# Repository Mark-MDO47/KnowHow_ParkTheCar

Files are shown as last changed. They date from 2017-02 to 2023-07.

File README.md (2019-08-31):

# KnowHow_ParkTheCar
inspired by TWIT.TV KnowHow Episode 178 about Arduino Collision Avoidance
https://twit.tv/shows/know-how/episodes/178

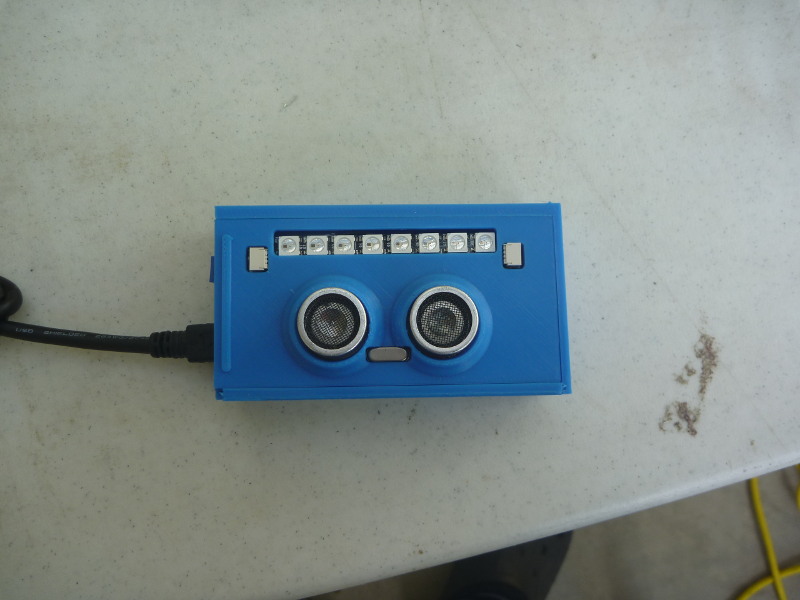
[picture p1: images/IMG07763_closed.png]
Finished version of Park The Car

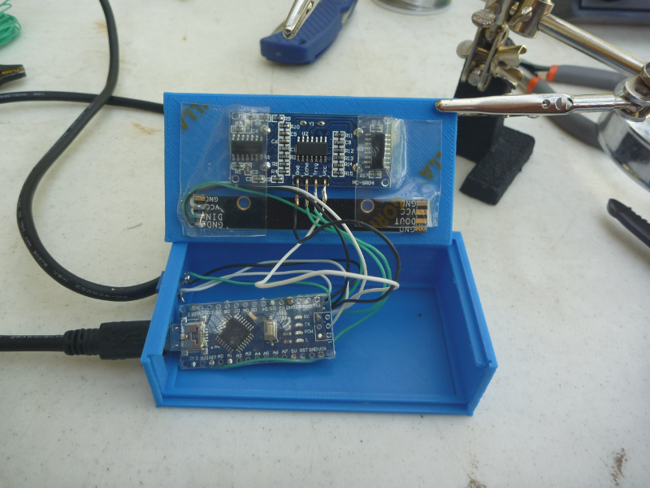
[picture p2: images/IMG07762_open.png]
Open version of Park The Car

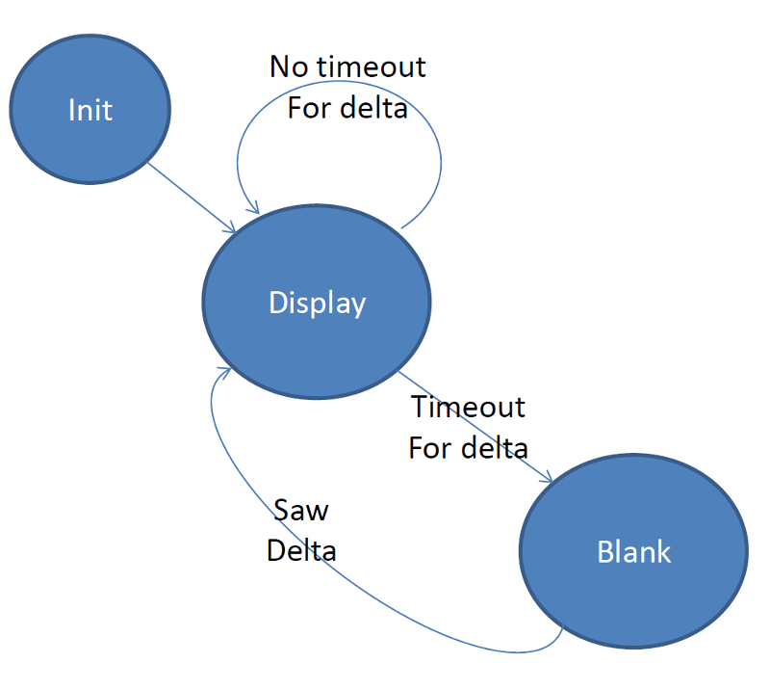
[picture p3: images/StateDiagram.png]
State Diagram of Park The Car


Arduino code rewritten extensively

Enclosure pretty much designed from scratch using OpenSCAD

Used VERY handy OpenSCAD routine from WarrantyVoider, published May 26, 2011 http://www.thingiverse.com/thing:8812
see README_attributions

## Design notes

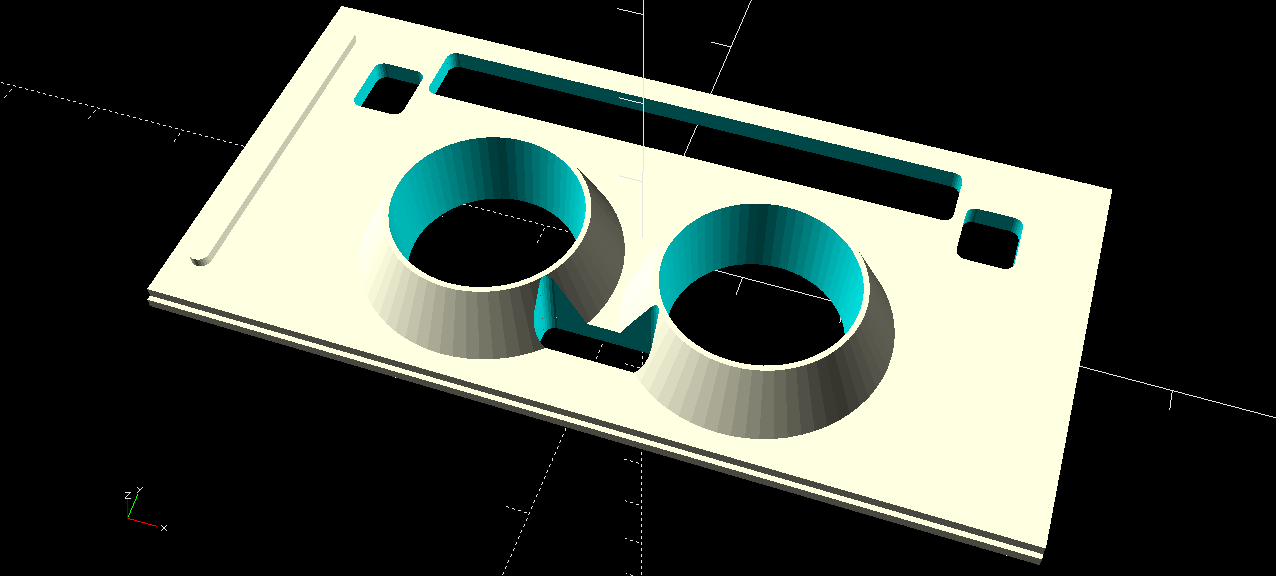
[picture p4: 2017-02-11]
images/top_HC-SR04.png

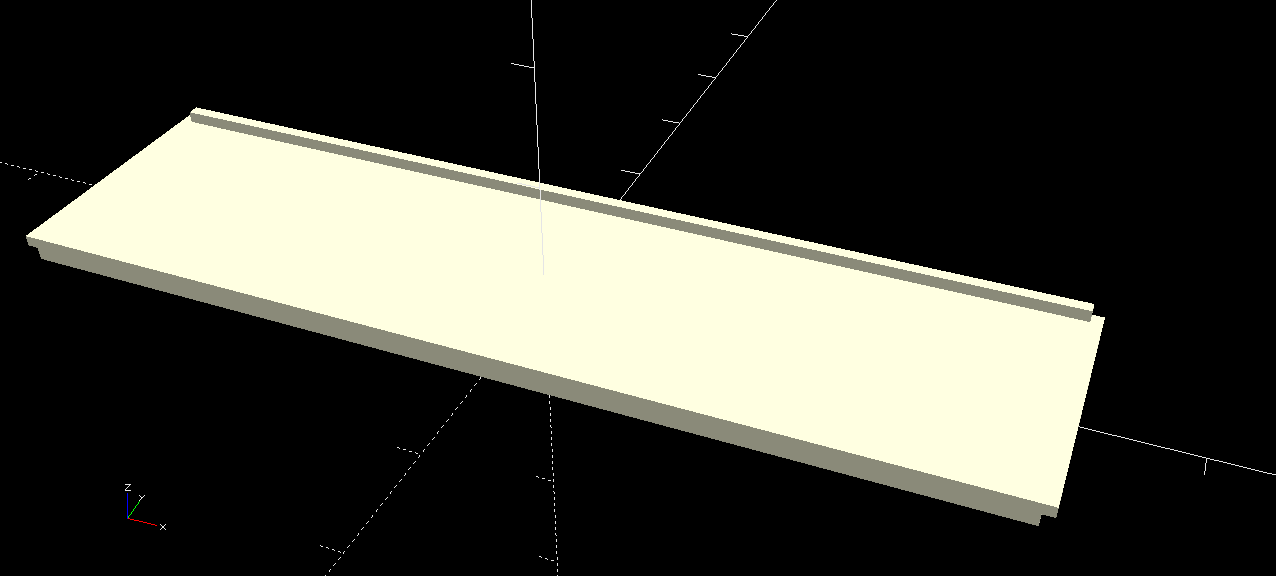
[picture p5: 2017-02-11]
images/side_HC-SR04.png

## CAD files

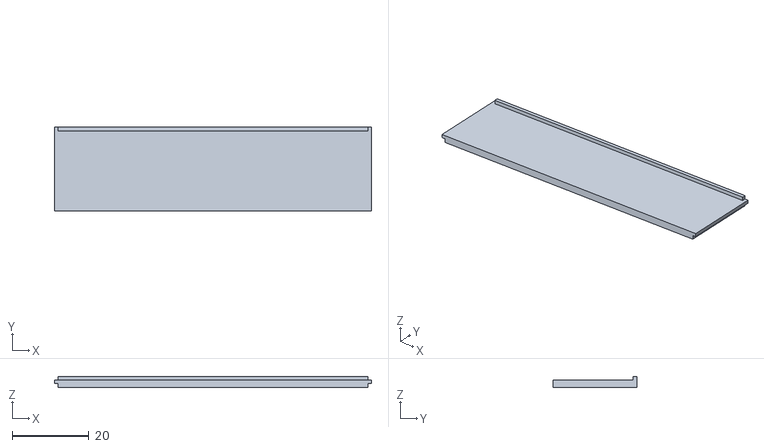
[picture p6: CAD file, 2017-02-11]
3D_Print_Files/side_HC-SR04.stl
82.8 x 21.9 x 3.00

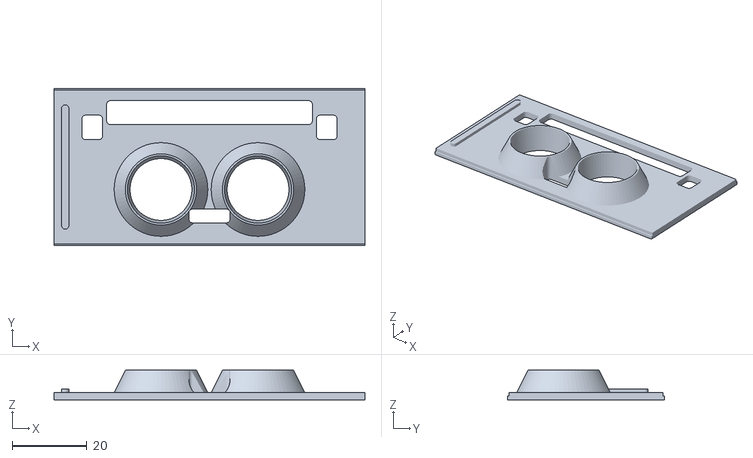
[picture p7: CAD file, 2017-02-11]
3D_Print_Files/top_HC-SR04.stl
83.0 x 42.0 x 8.00

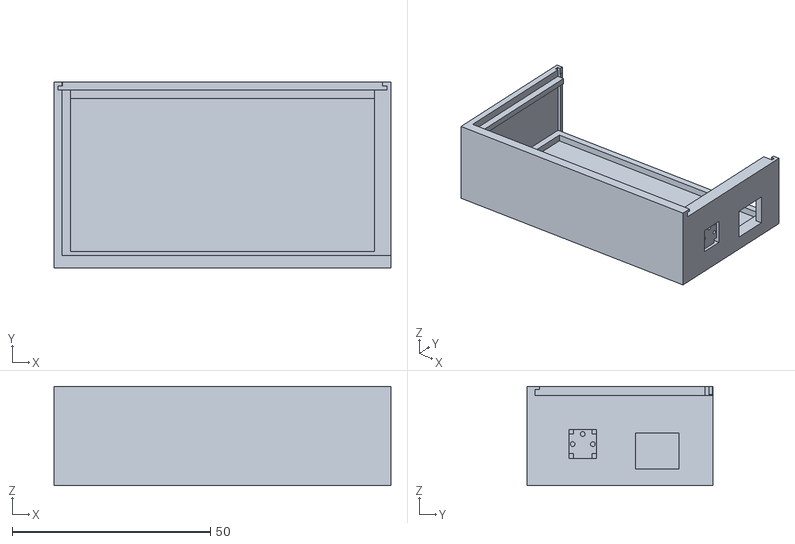
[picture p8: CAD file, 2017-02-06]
3D_Print_Files/box_HC-SR04.stl
85.0 x 47.0 x 25.0

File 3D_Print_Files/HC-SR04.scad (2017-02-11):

/* HC-SR04 enclosure
   2017-01-20 Mark Olson

*/


// VERY handy routine from WarrantyVoider, published May 26, 2011
use<roundCornersCube.scad> // http://www.thingiverse.com/thing:8812

/*

plate = top of box, rectangle
uson  = ultrasonic sensor HC-SR04
led   = LED strip (8 LEDs)
pot   = trimmer pot in UXcell type package 3362P-103

uson:
    Measured total rectangle skinny 20.25 mm (without connectors)
    Measured total rectangle skinny 26.68 mm (with connectors)
    Measured connector sticks out    6.43 mm (use 10 for room in box)
    Measured total rectangle long   45.55 mm
    Measured center circle to end of connector sticks out = 16.555 mm

    measured inner circle is 16.0
    measured make circle 16.4 mm diameter; 8.2 mm radius
    measured outer edge to outer edge circle 42.3 mm
    measured center circle to circle = 42.3 - 16.4 = 25.9

    measured rect hole bottom to top circle is 16.9 mm us 
    measured rect skinny is 3.6 mm use 3.7 mm
    measured true rect hole nearest to top circle is 16.9 - 3.6 = 13.3 mm
    measured true rect hole center to center circle = 16.9 - (16+3.7)/2 = 7.05 mm
    measured rect wide is 10 mm use 11

*/

wall_width = 2; // mm for plate and for slot and for box
h_slot_clearance       = 1.0;   // mm height clearance for lid fitting with box
w_slot_clearance       = 0.5;   // mm width clearance for lid fitting with box

// Bounding dimensions of entire top plate

plate_totl_height =  8;   // mm including eyes, width of plate, and everything
plate_slot_height =  wall_width;   // mm 
plate_totl_long   = 83.0; // mm 
plate_totl_skinny = 43;   // mm 

box_totl_height   = 25;   // mm including plate_slot_height but not plate_totl_height
box_totl_long     = plate_totl_long + wall_width;
box_totl_skinny   = plate_totl_skinny+2*wall_width;

// position offset of ultrasonic sensor with respect to plate center-to-center

uson_length_offset    =  0.0;   // mm
uson_width_offset     = -6.0;   // mm

// dimensions of ultrasonic sensor portion of plate

uson_otr_eye_radius   = 13.5;  // mm outer_eye
uson_inr_eye_radius   =  8.2;  // mm inner_eye - room for device
uson_otr_eye_nwby     =  4;    // mm factor for outer eye
uson_inr_eye_wdby     =  1;    // mm slope factor for inner eye
uson_eye_ctr2ctr      = 25.9;  // mm center eye circle to circle
uson_rect_skinny      =  3.7;  // mm skinny dimension rectangle hole - room for device
uson_rect_long        = 11;    // mm long dimension rectangle hole - room for device
uson_rect_cnctr_clear = 10;    // mm clearance in skinny direction - includes 2 mm for box slide
uson_eye_rect_ctr2ctr =  7.05; // mm center eye to rect

// position offset of ultrasonic sensor with respect to plate center-to-center

leds_length_offset    = 0.0;   // mm
leds_width_offset     = 12.0;  // mm

// dimensions of LED strip portion of plate

leds_rect_skinny      =  8.45; // mm
leds_rect_long        = 67.1;  // mm
leds_holes_ctr2ctr    = 35.15; // mm (on bottom)
leds_holes_radius     =  1.7;  // mm
leds_cnctr_skinny     =  5.56; // mm (on bottom)
leds_cnctr_long       = leds_rect_long; // mm
leds_cnctr_justone    =  4.5;  // mm (one on each side)
leds_led_skinny       =  5.4;  // mm (on top)
leds_led_long         = 53.9;  // mm

// dimensions of 3362P package trimmer pot

pot_w_clearance       = 0.2;   // mm clearance width
pot_h_clearance       = 0.2;   // mm clearance width
pot_w_outside         = 6.71 + 0.1; // mm outside dimension
pot_h_outside         = 7.04 + 0.1; // mm outside dimension
pot_lead_to_lead      = 2.54;       // mm vert/horiz between leads in x/y direc
pot_h_low_leads       = 3.53 + 0.5*pot_h_clearance; // mm height two leads
pot_h_hi_lead         = 6.07 + 0.5*pot_h_clearance; // mm height one lead
pot_w_low_lead_1      = (pot_w_outside - 2*pot_lead_to_lead)/2 +0.5*pot_w_clearance; // mm
pot_w_hi_lead         = pot_w_low_lead_1 + pot_lead_to_lead; // mm
pot_w_low_lead_2      = pot_w_hi_lead + pot_lead_to_lead; // mm

// dimensions of USB connector
usb_w_outside = 10.7; // mm outer width  of plug going into nano
usb_h_outside =  8.8; // mm outer height of plug going into nano
// 7.4 mm = top to bottom nano




module eye_outer(radius, narrowby, centertocenter, height, myfn) {
    union() {
        // outer eye of ultrasonic sensor is like to volcano walls
        translate([centertocenter/2.0+uson_length_offset,uson_width_offset,0])
            cylinder(r1=radius, r2=radius-narrowby, h=height, $fn=myfn);
        translate([-centertocenter/2.0+uson_length_offset,uson_width_offset,0])
            cylinder(r1=radius, r2=radius-narrowby, h=height, $fn=myfn);
    }
}   // end module eye_outer()

module eye_inner(radius, narrowby, centertocenter, height, myfn) {
    union() {
        // inner eye of ultrasonic sensor is the cutout to hold the microphone/speaker
        translate([centertocenter/2.0+uson_length_offset,uson_width_offset,-0.5])
            cylinder(r1=radius, r2=radius-narrowby, h=height+1, $fn=myfn);
        translate([-centertocenter/2.0+uson_length_offset,uson_width_offset,-0.5])
            cylinder(r1=radius, r2=radius-narrowby, h=height+1, $fn=myfn);
    }
}   // end module eye_inner()

// this module makes a plate for the top with rounded edges near the slot
//     seems to exceed some OpenSCAD limit; does not draw well
module roundrectplate(platelength,platewidth,plateheight,plateround) {
    rotate(v=[0,1,0], a=90) roundCornersCube(plateheight,platewidth,platelength, 1);
}

module plate(totalheight, platelength, platewidth, plateslotheight, bumpheightfract, nothing_bump_triangle) {
    // either do the raised bump or the triangular cutout or neither
    difference() {
        union() {
            translate([0,0,plateslotheight/2.0])
                // using roundCornersCube here would exceed some limit and gets unwanted faces
                // roundrectplate(platelength,platewidth-w_slot_clearance,plateslotheight,platelength, 1);
                cube(size = [platelength,platewidth-w_slot_clearance,plateslotheight], center = true);
            if (nothing_bump_triangle == 1) {
                translate([-(platelength/2)+3.0,0,0.99*totalheight/bumpheightfract]) roundCornersCube(2,0.8*platewidth,totalheight/bumpheightfract, 1);
            }
        }
            if (nothing_bump_triangle == 2) {
                // $fn=3 forces a triangular shape
                translate([-.85*platelength/2,0,1.01*plateslotheight/2.0]) cylinder(plateslotheight/2.0, 5, 7,$fn=3); // triangular cutout
            }
    }
}   // end module plate()

module side(plateslotheight, platelength, platewidth) {
    union() {
        translate([0,0,0.5*plateslotheight]) cube(size = [platelength,platewidth,plateslotheight], center = true);
        translate([0,0,0.77*plateslotheight]) cube(size = [platelength+plateslotheight-0.1,platewidth,0.46*plateslotheight], center = true);
    }
        translate([0,0.5*platewidth-0.25*plateslotheight,0.75*plateslotheight]) cube(size = [platelength,1,1.5*plateslotheight], center = true);
}   // end module side()

module top(totalheight, platelength, platewidth, plateslotheight) {
    difference() {
        union() {
            eye_outer(radius=uson_otr_eye_radius, narrowby=uson_otr_eye_nwby, centertocenter=uson_eye_ctr2ctr, height=totalheight, myfn=64);
            plate (totalheight, platelength, platewidth-plateslotheight/2.0, plateslotheight, bumpheightfract=4.0, nothing_bump_triangle = 1);
            plate (totalheight, platelength, platewidth, plateslotheight/2.0, bumpheightfract=4.0, nothing_bump_triangle = 0);
        }
        union() {
            // cut hole for ultrasonic sensor "eyes"
            eye_inner(radius=uson_inr_eye_radius, narrowby=-uson_inr_eye_wdby, centertocenter=uson_eye_ctr2ctr, height=2+totalheight, myfn=64);
            // cut hole for ultrasonic sensor "can" component
            translate([uson_length_offset,-uson_eye_rect_ctr2ctr+uson_width_offset,0.5*totalheight])
                roundCornersCube(uson_rect_long,uson_rect_skinny,1.1*totalheight,1);
            // cut hole for LED long-skinny rectangle (LEDs shine through this)
            translate([leds_length_offset,leds_width_offset+(leds_rect_skinny-leds_led_skinny)/2+1,0.5*totalheight]) roundCornersCube(leds_led_long+1,leds_led_skinny+1,1.1*totalheight,1);
            // cut two holes to make room for connectors at ends of LEDs
            translate([leds_length_offset+(leds_cnctr_long-leds_cnctr_justone)/2,leds_width_offset-(leds_rect_skinny-leds_cnctr_skinny)/2,0.5*totalheight]) roundCornersCube(leds_cnctr_justone+1,leds_cnctr_skinny+1,1.1*totalheight,1);
            translate([leds_length_offset-(leds_cnctr_long-leds_cnctr_justone)/2,leds_width_offset-(leds_rect_skinny-leds_cnctr_skinny)/2,0.5*totalheight]) roundCornersCube(leds_cnctr_justone+1,leds_cnctr_skinny+1,1.1*totalheight,1);
        }
    }
}   // end module top()
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

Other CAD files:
3D_Print_Files/roundCornersCube.scad

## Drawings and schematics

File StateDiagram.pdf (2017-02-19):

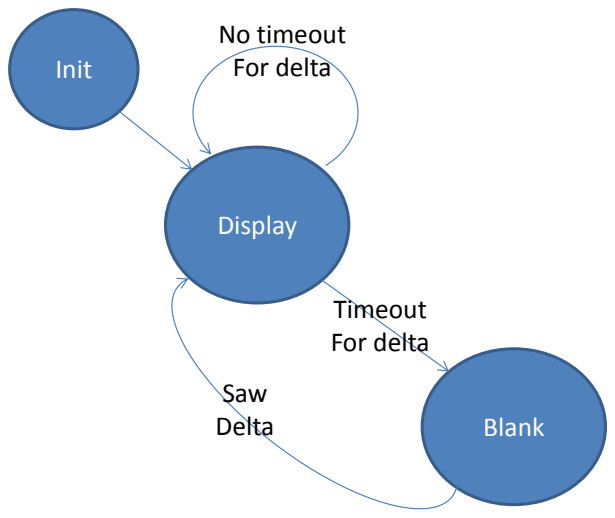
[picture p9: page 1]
Init; Display; No timeout For delta; Blank; Timeout For delta; Saw Delta

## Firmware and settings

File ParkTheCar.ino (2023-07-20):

// We're including two Libraries, "Ultrasonic.h" and "FastLED.h"
// FastLED.h gives us the ability to addres the WS2812 LEDs
// "Ultrasonic.h" allows us to trigger and read the ultrasonic sensor
#include "Ultrasonic.h"
#include "FastLED.h"

// Mark Olson 2016-09
//
// adapted from TWIT-TV Know How https://twit.tv/shows/know-how/episodes/178
//     major kudos to Fr. Robert Ballecer and Bryan Burnett for their show
//             and for pointing me to the FastLED library
//     major kudos to Daniel Garcia and Mark Kriegsman for the FANTASTIC FastLED library and examples!!!
//
// My buddy Jim and I pretty much re-wrote the code for our own sensibilities
//
// Discovered it REALLY helps to use AREF when using an analog signal; maybe that is needed due to
//    using inexpensive clone Arduino nano
// Also using a software hysteresis. When the potentiometer is found to be in a certain interval
//    then we make it "sticky" by extending that interval a bit on both sides (POT_HYST_DELTA)
//
//
// I am using an Arduino Nano with a USB mini-B connector
//   example: http://www.ebay.com/itm/Nano-V3-0-ATmega328P-5V-16M-CH340-Compatible-to-Arduino-Nano-V3-Without-Cable/201804111413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
//            V3.0 ATmega328P 5V 16M CH340 Compatible to Arduino Nano V3
//            http://www.mouser.com/pdfdocs/Gravitech_Arduino_Nano3_0.pdf
//
// uses 8-LED PIXEL STICK WS2812
//   example: http://www.readytoflyquads.com/rtfpixel-stick-8x-rgb-leds
//            This Programmable LED bar has 8 RGB WS2812 LED's set up in series.  These bars are 70mm long and 9mm wide with two mounting holes 35mm apart.
//
// uses Ultrasonic Module HC-SR04 Distance Measuring Transducer Sensor
//   example: http://www.ebay.com/itm/Ultrasonic-Module-HC-SR04-Distance-Measuring-Transducer-Sensor-for-Arduino-FO-/291548991993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
//
// uses Uxcell 50K-ohm Trimmer Potentiometer. I used the 3386P-package top-adjustment version
//   example: https://smile.amazon.com/gp/product/B00G9JSCUQ/ref=oh_aui_detailpage_o02_s00?ie=UTF8&psc=1
//
//
// 2017-01 MDO: re-wrote pot hysterisis code, which suffered from two-person split-personality stream-of-consciousness coding syndrome.
//    Using AREF, sampling pot 500 times gives a range of [0,6] (example: values 708 through 713). Hysterisis parameter is set at 4 which
//    will handle this but means that we can only have intervals of 8 since hysterisis < interval size. Thus 128 intervals.
//
// connections:
// 
// Nano pin 5V      LEDstick VCC
// Nano pin GND     LEDstick GND
// Nano pin D-3     LEDstick DIN
//
// Nano pin 5V      SR04 VCC
// Nano pin GND     SR04 GND
// Nano pin D-13    SR04 Trig
// Nano pin D-12    SR04 Echo
//
// Nano pin 5V      Pot VCC (one side)
// Nano pin AREF    Pot same pin as above
// Nano pin GND     Pot GND (other side)
// Nano pin A-1     Pot middle

// Recommendations - of course I ignored these!  ;^)
//    Before connecting the WS2812 to a power source, connect a big capacitor from power to ground. A cap between 100microF and 1000microF should be good. Try to place this cap as close to your WS2812 as possible.
//    Electrolytic Decoupling Capacitors 
//
//    Placing a small-ish resistor between your Arduino's data output and the WS2812's data input will help protect the data pin. A resistor between 220 and 470 O should do nicely. Try to place the resistor as close to the WS2812 as possible.
//
//    Keep Wires Short!

// We are using an 8-LED stick
#define NUM_LEDS 8

// We'll be using Digital Data Pin #3 to control the WS2812 LEDs
#define LED_DATA_PIN 3

// we will use analog pin A1 to read the potentiometer
//   leaves a little space between that and AREF
// BE SURE TO CONNECT THE AREF PIN!!! MAKES READINGS MUCH LESS NOISY
// the potentiometer adjusts the desired car position (fine grain)
#define ANLG_PIN 1

// This tells the ultrasonic library that the trigger pin is on digital 13
// This also tells the ultrasonic library that the echo pin is on digital 12
#define ULTRA_TRIG_PIN 13
#define ULTRA_ECHO_PIN 12


// we use the range value from the Ultrasonic sensor to decide we are in one of
//    ULTRA_REGION_NUM display ranges (or OFF)
//    ranges are mapped to appropriate entry in led_ultra_range_mapping[] array
#define ULTRA_REGION_NUM 7 // number of valid ranges; index = 0 means OFF

// These are the definitions for our software hysteresis
// NOTE FIXME DEPENDS ON POT_RAW_NUM_INTVL BEING A POWER OF 2 AND EXACTLY DIVISIBLE INTO COUNTS
#define POT_RAW_NUM_COUNTS 1024 // so max val is 1023
#define POT_RAW_COUNTS_INTVL 8 // analog counts in each interval
#define POT_RAW_NUM_INTVL (POT_RAW_NUM_COUNTS/POT_RAW_COUNTS_INTVL) // number of intervals
#define POT_HYST_DELTA 4 // size extra size of hysteresis each side in counts; MUST be < (POT_RAW_NUM_COUNTS/POT_RAW_NUM_INTVL)
static int pot_intvl_prev = -99; // no hysterisis first time; this interval will match nothing
#define DEBUG_POT_HYSTERISIS(A) // Serial.print((A)) to debug

// approximate distances
// 50.8 cm or 20 inches min
// 66.04 cm or 26 inches van
// 81.28 cm or 32 inches middle
// 96.52 cm or 38 inches car
// 111.76 cm or 44 inches max
#define POT_DISTANCE_MIN_CM   50.8
#define POT_DISTANCE_MAX_CM  111.76
#define POT_DISTANCE_DELTA_CM ((POT_DISTANCE_MAX_CM-POT_DISTANCE_MIN_CM)/POT_RAW_NUM_INTVL)

// Creates an array with the length set by NUM_LEDS above
// This is the array the library will read to determine how each LED in the strand should be set
CRGB led_display[NUM_LEDS];
CRGB led_ultra_range_mapping[8 * NUM_LEDS] = { \
    CRGB::Black,   CRGB::Black,   CRGB::Black,   CRGB::Black,   CRGB::Black,   CRGB::Black,   CRGB::Black,   CRGB::Black,  \
    CRGB::Green,   CRGB::Green,   CRGB::Green,   CRGB::Green,   CRGB::Green,   CRGB::Green,   CRGB::Green,   CRGB::Green,  \
    CRGB::Orange,  CRGB::Orange,  CRGB::Green,   CRGB::Green,   CRGB::Green,   CRGB::Green,   CRGB::Green,   CRGB::Orange, \
    CRGB::Orange,  CRGB::Orange,  CRGB::Orange,  CRGB::Green,   CRGB::Green,   CRGB::Green,   CRGB::Green,   CRGB::Orange, \
    CRGB::Red,     CRGB::Red,     CRGB::Red,     CRGB::Red,     CRGB::Orange,  CRGB::Orange,  CRGB::Orange,  CRGB::Red,    \
    CRGB::Red,     CRGB::Red,     CRGB::Red,     CRGB::Red,     CRGB::Red,     CRGB::Orange,  CRGB::Orange,  CRGB::Red,    \
    CRGB::Red,     CRGB::Red,     CRGB::Red,     CRGB::Red,     CRGB::Red,     CRGB::Red,     CRGB::Orange,  CRGB::Red,    \
    CRGB::Red,     CRGB::Red,     CRGB::Red,     CRGB::Red,     CRGB::Red,     CRGB::Red,     CRGB::Red,     CRGB::Red};

int blnk_cnt = 0;
int blnk_on = 0;
#define BLNK_CNT_MAX 5

// Now we're going to initialize an instance from the Ultrasonic Sensor library with our pin numbers
// The sensor itself needs four leads: ground, vcc, trigger, and echo
Ultrasonic ultrasonic(ULTRA_TRIG_PIN,ULTRA_ECHO_PIN);

// copy_leds does the copying of the CRGB values
// also takes care of blinking
void copy_leds(int idx, CRGB *from, CRGB *to)
{
  for (int i = 0; i < NUM_LEDS; i += 1)
  {
    to[i] = from[i + NUM_LEDS * idx];
  }

  // do we need to blink the edges
  blnk_cnt += 1;
  blnk_cnt %= BLNK_CNT_MAX;
  if (0 == blnk_cnt) blnk_on ^= 1;
  if ((idx > 2) && (1 == blnk_on))
  {
    to[0] = CRGB::Black;
    to[NUM_LEDS-1] = CRGB::Black;
  }
}

int pot_intvl_with_hysterisis(int pot_read) {
    int pot_intvl = pot_read / POT_RAW_COUNTS_INTVL;
    DEBUG_POT_HYSTERISIS(pot_intvl_prev); DEBUG_POT_HYSTERISIS(" <-- pot_intvl_prev "); DEBUG_POT_HYSTERISIS(pot_intvl); DEBUG_POT_HYSTERISIS(" <-- pot_intvl_raw ");
    // now to check for hysterisis
    if ( (pot_intvl - pot_intvl_prev) == 1) {
        DEBUG_POT_HYSTERISIS((pot_read - POT_HYST_DELTA) / POT_RAW_COUNTS_INTVL ); DEBUG_POT_HYSTERISIS(" <-- hyst check due to +1 ");
        if ( ( (pot_read - POT_HYST_DELTA) / POT_RAW_COUNTS_INTVL )  == pot_intvl_prev) {
            pot_intvl = pot_intvl_prev;
            DEBUG_POT_HYSTERISIS(pot_intvl); DEBUG_POT_HYSTERISIS(" <-- pot_intvl_adjust due to +1 ");
        }
    } else if ( (pot_read - POT_HYST_DELTA) == -1) {
        DEBUG_POT_HYSTERISIS((pot_read - POT_HYST_DELTA) / POT_RAW_COUNTS_INTVL ); DEBUG_POT_HYSTERISIS(" <-- hyst check due to -1 ");
        if ( ( (pot_read + POT_HYST_DELTA) / POT_RAW_COUNTS_INTVL )  == pot_intvl_prev) {
            pot_intvl = pot_intvl_prev;
            DEBUG_POT_HYSTERISIS(pot_intvl); DEBUG_POT_HYSTERISIS(" <-- pot_intvl_adjust due to -1 ");
        }
    }   // end if might need hysterisis adjustment
    pot_intvl_prev = pot_intvl;
    return(pot_intvl);
}   // end Pot_intvl_with_hysterisis()

// with AREF and hysterisis don't need moving average
int pot_desired_distance() {
    int pot_read = analogRead(ANLG_PIN); // This checks the pot connected to Analog Pin - and gives us a value between 0-1024
    DEBUG_POT_HYSTERISIS(pot_read); DEBUG_POT_HYSTERISIS(" <-- analog ");
    // get potentiometer interval number [0,POT_RAW_NUM_INTVL)
    int pot_intvl = pot_intvl_with_hysterisis(pot_read);
    DEBUG_POT_HYSTERISIS(pot_intvl); DEBUG_POT_HYSTERISIS(" <-- intvl ");
    // convert to distance in cm (psuedo-rounded)
    int pot_dist = POT_DISTANCE_MIN_CM +0.5 + pot_intvl * POT_DISTANCE_DELTA_CM;
    Serial.print(pot_dist);
    Serial.print(" <-- dist");
    Serial.print("\n"); // don't use println so can use DEBUG_POT_HYSTERISIS()
    return(pot_dist);
}   // end pot_desired_distance()

// pot_dist is the desired distance
// ultra_distance is the actual distance
// approximate distances
// 50.8 cm or 20 inches min
// 66.04 cm or 26 inches van
// 81.28 cm or 32 inches middle
// 96.52 cm or 38 inches car
// 111.76 cm or 44 inches max

int calc_led_idx(int pot_dist, int ultra_dist) {
   int idx = 0;
   return(idx);  
}
#define POT_DISTANCE_MIN_CM   50.8
#define POT_DISTANCE_MAX_CM  111.76
#define POT_DISTANCE_DELTA_CM ((POT_DISTANCE_MAX_CM-POT_DISTANCE_MIN_CM)/POT_RAW_NUM_INTVL)

// setup()
//   initializes FastLED library for our config
//   initializes serial port
void setup()
{
  FastLED.addLeds<NEOPIXEL,LED_DATA_PIN>(led_display, NUM_LEDS);
  Serial.begin(9600);

  Serial.println("setup");
  
  delay(100);
}

// loop()
//    sorry; gets a little complex here ... ;^)
//
//    we read the potentiometer and calculate its distance setting using hysteresis
//       note: normally the potentiometer only moved during calibration
//    we compare this desired distance with that from LPF
//    If  "no ultrasound bounce" return, special case index into led_ultra_range_mapping[]
//    we calculate what region the LPF range is in
//    the index of that region is the index into led_ultra_range_mapping[] for display
//       so we call copy_leds() with that index
//    copy_leds() takes care of LED blinking using a count based on time
//
void loop() {
  
  static int idx = 0;
  static int range_regions_min[ULTRA_REGION_NUM] = { 42, 32, 27, 17, 12, 7 };
  static int range_regions    [ULTRA_REGION_NUM] = { 42, 32, 27, 17, 12, 7 };
  static int range;
  static int potIntvl = 0; // number calculated from potentiometer using hysteresis; previous at entry
  static int once = 0;

  if (0 == once)
  {
    once = 1;
    Serial.println("loop");
  }

  // this gives us a number of centimeters we want to call good
  int pot_dist = pot_desired_distance();
  
  // the range reading from the Ultrasonic sensor in centimeters
  int ultra_dist=(ultrasonic.Ranging(CM));
  idx = calc_led_idx(pot_dist, ultra_dist);
  //Serial.println(idx);
  // we want [0,ULTRA_REGION_NUM] currently [0-7] (note: endpoint inclusive
  // see what region idx we are in - farthest away is smallest idx; idx=7 is LED OFF


  copy_leds(idx, led_ultra_range_mapping, led_display);
  FastLED.setBrightness(60);
  FastLED.show();
  
  delay(100);
}

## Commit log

2017-02-06 initial version of files
    [HC-SR04.scad, side_HC-SR04.stl, top_HC-SR04.stl]
2017-02-06 oops - stl not gcode
    [box_HC-SR04.stl]
2017-02-06 we wanted stl not gcode
2017-02-11 make top 0.5 mm wider
    [HC-SR04.scad, side_HC-SR04.stl, top_HC-SR04.stl]
2017-02-11 move analog pin - space from AREF; update comments
2017-02-12 pictures of assembly
2017-02-19 vastly improved potentiometer hysterisis
    vastly improved potentiometer hysterisis; still need to fix interval selection
    [ParkTheCar.ino]
2019-08-31 move 3D print files to 3D_Print_Files directory
    [HC-SR04.scad, box_HC-SR04.stl, roundCornersCube.scad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]
